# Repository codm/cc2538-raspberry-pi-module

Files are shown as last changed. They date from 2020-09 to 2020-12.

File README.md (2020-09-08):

# cod.m ZigBee CC2538 Raspberry Pi module
[ZigBee CC2538 Raspberry Pi Coordinator](https://shop.codm.de/automation/zigbee/29/zigbee-cc2538-raspberry-pi-modul) - a ZigBee Coordinator designed for the GPIO of the Raspberry Pi running Z-Stack Firmware 3.0.x.
The used CC2538 module has an onboard CC2592 PA/LNA for range extension. Together with an external antenna this should make - depending on your surrounding - for a very good coverage.

According to [koenkk](https://github.com/Koenkk/Z-Stack-firmware/tree/master/coordinator) the CC2538 allows for up to 100 direct children and 200/400 routes directly on the coordinator. Keep in mind that the size of a ZigBee mesh is not defined by the count of possible direct children at the coordinator, see https://www.zigbee2mqtt.io/information/FAQ.html#i-read-that-zigbee2mqtt-has-a-limit-of-20-devices-is-this-true

If you are interessted in the development of the module, take a look here: https://github.com/Koenkk/zigbee2mqtt/issues/1568#issuecomment-670571253

The corresponding eagle library for the CC2538 module, including 3D model (thanks to @co-Palko), can be found here: https://github.com/codm/eagle-libraries

You can buy a ready built coordinator, including external antenna at our webshop: https://shop.codm.de/automation/zigbee/29/zigbee-cc2538-raspberry-pi-modul

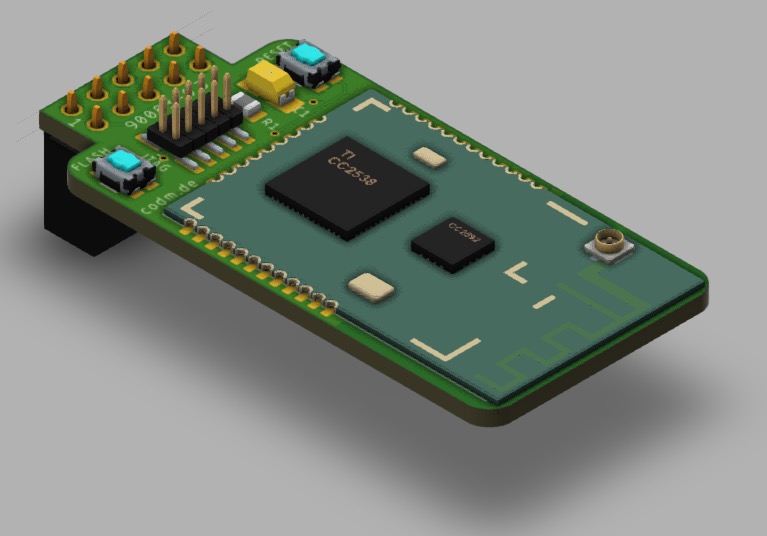
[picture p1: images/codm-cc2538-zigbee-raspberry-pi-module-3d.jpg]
cod.m CC2538 ZigBee Raspberry Pi Module


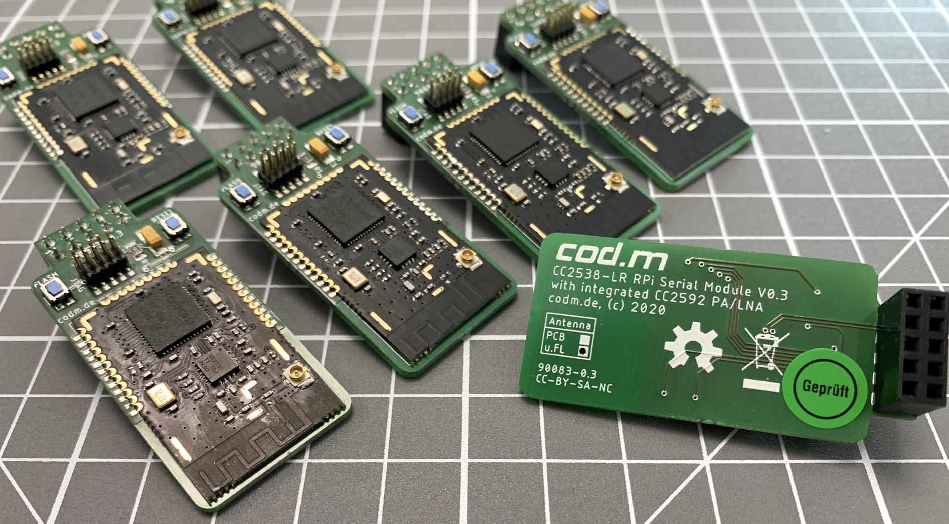
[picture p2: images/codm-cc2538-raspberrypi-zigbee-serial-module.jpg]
cod.m CC2538 ZigBee Raspberry Pi Module PCB's


# Running
To us the module directly on the serial interface on the GPIO of the Raspberry Pi, you have to free it up first. Either completely or by moving the Bluetooth UART to the mini-uart.

See  https://www.raspberrypi.org/documentation/configuration/uart.md
Also explained in the manual (german): [Anleitung cod.m ZigBee CC2538 Raspberry Pi Modul](https://shop.codm.de/media/pdf/3f/e7/be/20200901_ZigBee_CC2538_Raspberry_Pi_Modul_V03_Datenblatt_Anleitung-codm.pdf) 

# Antenna
We recommend to use only external antennas as the module is close to the WiFi and Bluetooth module/antenna on the Raspberry Pi. But if you want to use the attached PCB antenna, rotate the resistor pointing to the u.FL socket by 90° so it connects the PCB trace.

Well, that's a feature of the used CC2538 module 😉

# Firmware
The firmware is the same used on the modkam module, but adapted for direct UART use by @reverieline: https://github.com/reverieline/CC2538-CC2592-ZNP/

You can flash the firmware either by JTAG or directly from the Raspberry Pi using [cc2538-prog](https://github.com/1248/cc2538-prog/). 
Keep in mind, you have to flash a firmware with a serial bootloader (SBL) to use this feature again, e.g. `MODKAMRU_V3_UART-no-flow-control_with_SBL.hex`.

## JTAG
The 2x05 header is following the common [JTAG-Cortex-M0](https://www.segger.com/products/debug-probes/j-link/accessories/adapters/9-pin-cortex-m-adapter/) Layout.

The original adapter for the "normal" 20-pin JTAG layout is quite expensive, so we've built our own. You'll find alternatives around the web or get in touch with us.

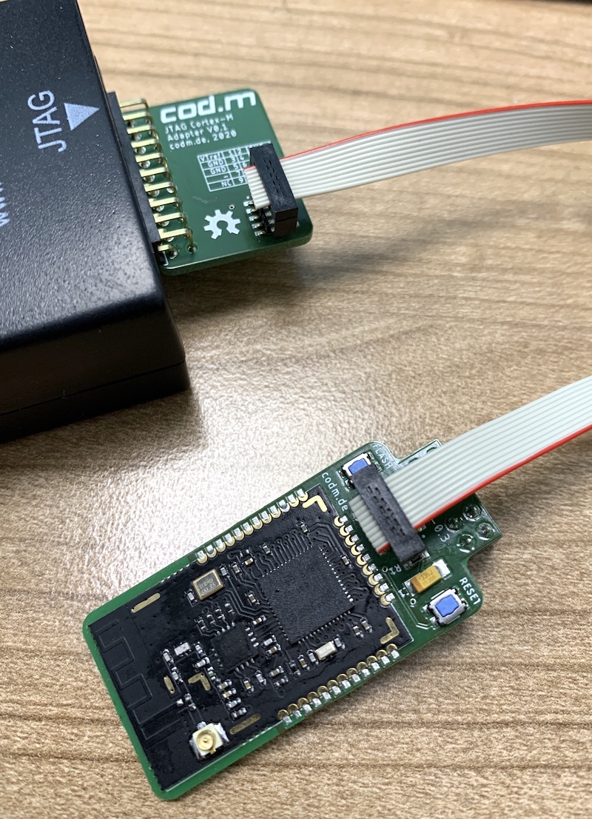
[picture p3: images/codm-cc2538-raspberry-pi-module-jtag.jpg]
cod.m CC2538 Zigbee Raspberry Pi Module JTAG


## Serial via GPIO
Install and compile [cc2538-prog](https://github.com/1248/cc2538-prog/).

While connected and powered through the Pi, hold down the `flash` button on the module and press `reset` shortly while still holding `flash`. The CC2538 should now be in the bootloder.

Then execute `./cc2538-prog -d /dev/ttyAMA0 -f MODKAMRU_V3_UART-no-flow-control_with_SBL.hex`

The output should look like this: 
```
ping ok
Bootloader detected
Erasing page 0
Erasing page 1
[...]
Erasing page 254
Erasing page 255
Writing 16 bytes to 0x00200000
Writing 16 bytes to 0x00200010
[...]
Writing 16 bytes to 0x0023C7F0
Writing 12 bytes to 0x0027FFD4
```

After that reset the module using the corresponding button. 
It happened sometimes that I had to replug the module to get it to work again. 

# Thanks
* @koenkk Z-Stack Firmware - https://github.com/Koenkk/Z-Stack-firmware
* @reverieline UART Version of the Z-Stack firmware - https://github.com/reverieline/CC2538-CC2592-ZNP/tree/master/MODKAMRU_V3
* @co-Palko 3D model of the chinese module - https://github.com/co-Palko
* @1248 cc2538-prog - https://github.com/1248/cc2538-prog/

# License
[CC-BY-SA 3.0](https://creativecommons.org/licenses/by-sa/3.0/)

cod.m GmbH, Patrik Mayer, 2020

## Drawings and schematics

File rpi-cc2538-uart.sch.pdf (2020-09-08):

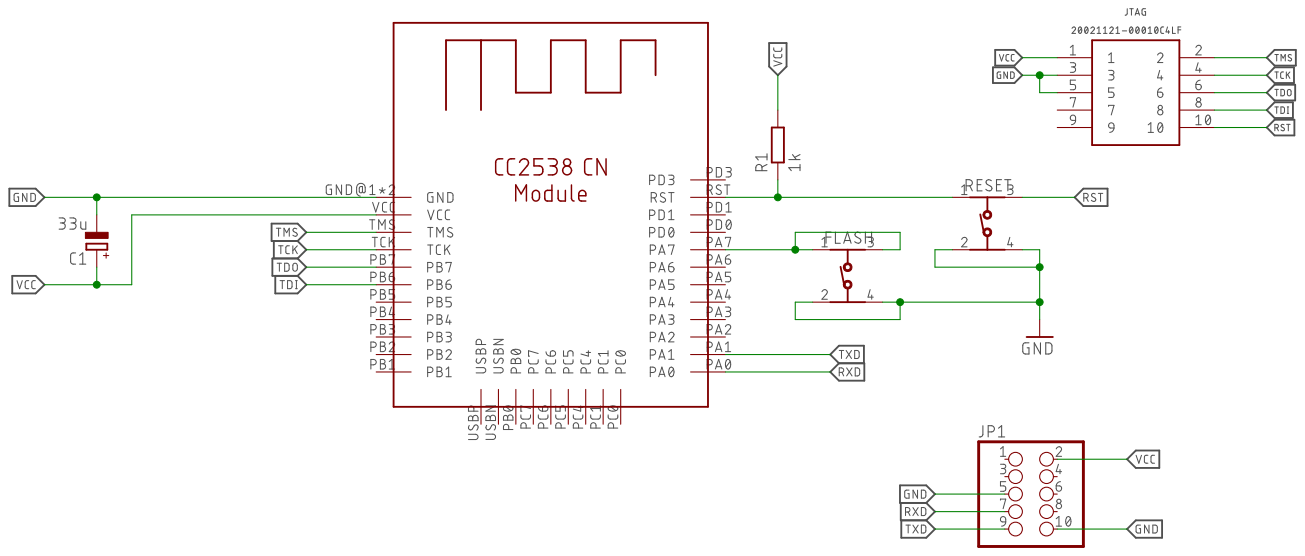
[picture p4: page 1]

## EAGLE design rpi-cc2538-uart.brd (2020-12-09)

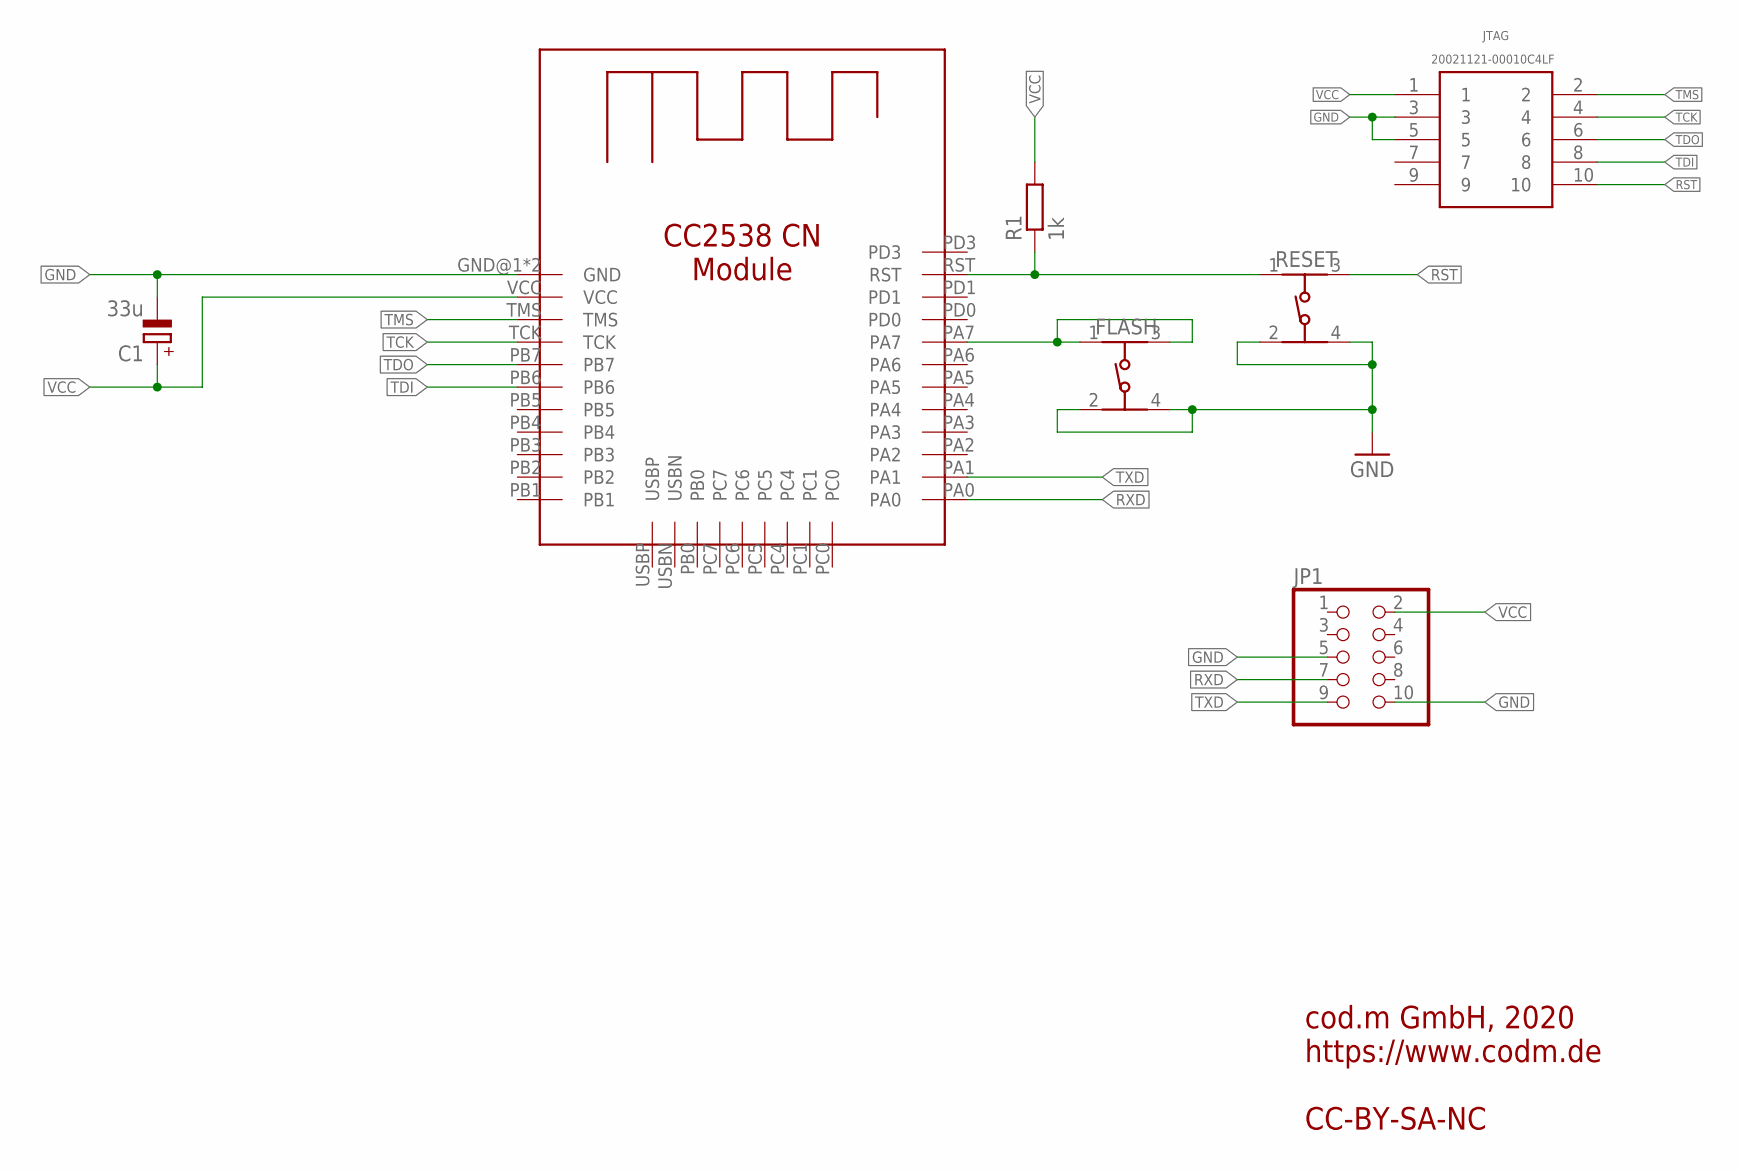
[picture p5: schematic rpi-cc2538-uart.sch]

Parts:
C1: 33u; A/3216-18W
FLASH: 434153017835
JP1: PINHD-2X5; 2X05
JTAG: 20021121-00010C4LF; 2002112100010C4LF
R1: 1k; R0805
RESET: 434153017835
U$1: CC2538-CN

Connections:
FLASH: FLASH.1, FLASH.3 (2), U$1.PA7
GND: C1.-, FLASH.2 (3), FLASH.4, JP1.5, JP1.10, JTAG.3, JTAG.5, RESET.2 (3), RESET.4, U$1.GND@1 (GND), U$1.GND@2 (GND)
RST: JTAG.10, R1.1, RESET.1, RESET.3 (2), U$1.RST
RXD: JP1.7, U$1.PA0
TCK: JTAG.4, U$1.TCK
TDI: JTAG.8, U$1.PB6
TDO: JTAG.6, U$1.PB7
TMS: JTAG.2, U$1.TMS
TXD: JP1.9, U$1.PA1
VCC: C1.+, JP1.2, JTAG.1, R1.2, U$1.VCC

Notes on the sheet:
cod.m GmbH, 2020 https://www.codm.de CC-BY-SA-NC

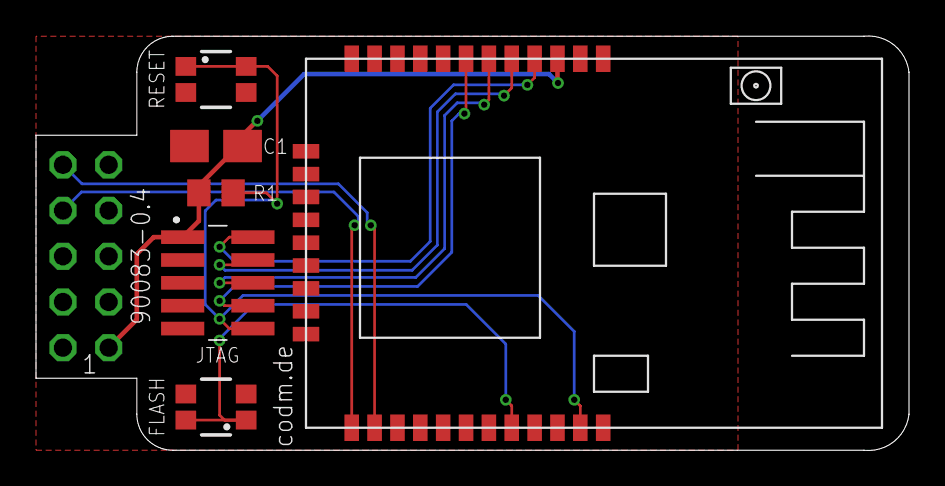
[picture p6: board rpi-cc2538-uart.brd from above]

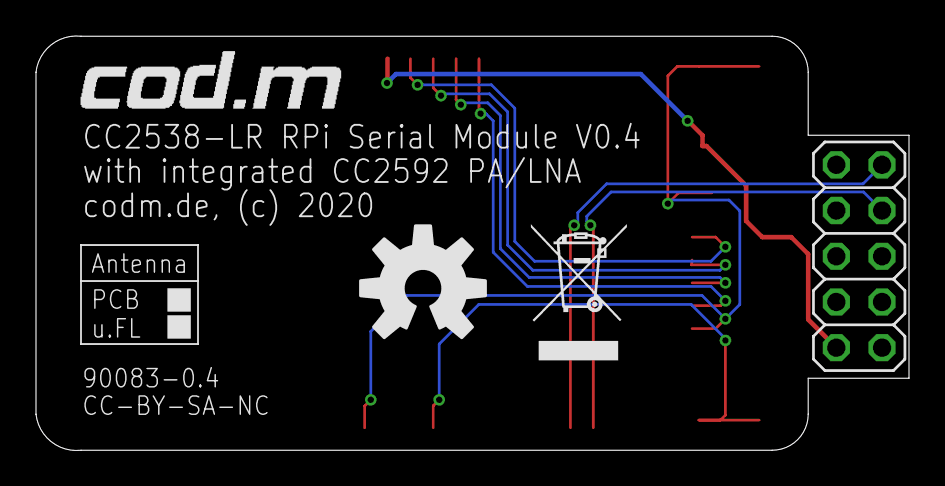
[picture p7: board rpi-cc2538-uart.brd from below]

Board: 2 copper layers, 48.5 x 23.0 mm, 10 parts (4 on the bottom side), 10 nets.

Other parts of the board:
U$2: CODM-LOGO
U$3: WEEE-LOGO-5MM
U$4: OSHW-LOGO-L

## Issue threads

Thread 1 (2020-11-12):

RX - TX Swapped in PDF schema

miqmago, 2020-11-12:
I've seen that RX and TX are swapped in JP1, Is that right?

Raspberry PI Pinout https://www.raspberrypi.org/documentation/usage/gpio/:
```

            3V3| 1 | 2  |5V
    GPIO2 (SDA)| 3 | 4  |5V
    GPIO3 (SCL)| 5 | 6  |GND
 GPIO4 (GPCLK0)| 7 | 8  |GPIO14 (TXD)
            GND| 9 | 10 |GPIO15 (RXD)
```

But in https://github.com/codm/cc2538-raspberry-pi-module/blob/master/rpi-cc2538-uart.sch.pdf the JP1 header is configured like this:

```
   | 1 | 2  |VCC
   | 3 | 4  |
GND| 5 | 6  |
RXD| 7 | 8  |
TXD| 9 | 10 |GND
```

codmpm, 2020-11-13:
Hey @miqmago, yes that is correct.
TX is where the data is sent from (transceived), so at the Pi that data is received. Thus TX is connected to RX and vice versa.

The boards we currently sell are based on this repo, so they do work.

Closed 2020-11-13.

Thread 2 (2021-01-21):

Gerber and BOM

Unb9rn, 2021-01-21:
Any plans to release Gerber and BOM for this? It looks like it's impossible to order prebuild board from russia, so it would be great if one could just manufacture this without having to go to CAM processing in Eagle first...

codmpm, 2021-01-21:
Hey @Unb9rn,

as the gerbers should be deppendant on the DRU files from the board house, it should be better to generate them with eagle. Should be possible with the free variant.

The BOM is rather simple and could also be exported from eagle.

Cheers,
Patrik

Closed 2021-01-21.

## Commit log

2020-09-08 first public release
    [rpi-cc2538-uart.brd, rpi-cc2538-uart.sch]
2020-11-13 minor changes for new aisler dru
    [rpi-cc2538-uart.brd]
2020-12-09 cc2538 footprint with larger pads, refined groundplane
    [rpi-cc2538-uart.brd, rpi-cc2538-uart.sch]

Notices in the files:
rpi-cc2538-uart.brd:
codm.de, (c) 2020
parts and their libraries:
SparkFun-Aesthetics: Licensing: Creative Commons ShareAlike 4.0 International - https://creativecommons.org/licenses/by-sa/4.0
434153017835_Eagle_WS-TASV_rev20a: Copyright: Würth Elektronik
